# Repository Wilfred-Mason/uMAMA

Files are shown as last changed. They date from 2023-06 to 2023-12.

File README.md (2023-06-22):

# uMAMA
Repository for the development and research of a microfluidic biosignature detection device in the Whyte Lab at Mcgill

# Standard Operating Procedure: uMAMA
## Hardware Setup
**Equipment list**:
1. uMAMA module
2. USB cables for camera and arduino
3. USB hub for field computer

### Instructions
1. Turn field computer on
2. Plug USB hub into field computer (make sure the USB hub switch is on)
3. Plug camera and arduino USB cables into USB hub
4. Wait 1 minute for the camputer to recognize the devices

## Software Setup
**List of Executable Python Scripts**
1. **Main.py**:
   This is your main script that will be used to take measurments with the uMAMA unit
   Run this everytime you need to take a new measurment. The script will prompt you to select
   the uMAMA that you are taking a measurment of and it will allow you to select sampling
   spots for the colours. This script will also save data into the RBG_Data.csv file in the
   respective uMAMA folder. It will also save the photo taken with its date in its folder with the
   format (uMAMA_#_MM-DD-YYYY_HH-MM-SS)
2. **Reset.py**:
   This is the script that will delete previously recorded data.
   You can either select which uMAMA's data to delete or you can delete all uMAMA data.
   This script should be run only before the first uMAMA measurment to delete all data.
3. **EditData.py**:
   This is the script that allows you to edit previous uMAMA data. It allows you to delete
   measurments for the uMAMAs. The script will prompt you for which uMAMA's data you want to
   edit. It will then display a list of all uMAMA measurments with their dates
   in the format (MM-DD-YYYY_HH-MM-SS)
4. **GenerateFigure.py**:
   This script allows you to generate a colour plot using the uMAMA data. It will prompt you
   for which uMAMA's data you would like to visualize. It will save the figure in their respective uMAMA
   folder.

### Intructions
**First Time Measurement**
1. Open Windows PowerShell
2. Enter the uMAMA directory via
   `cd uMAMA`
3. Run the reset script via
   `Python Reset.py`
4. When prompted for which uMAMA's data to delete, enter "a" for all
5. When prompted to confirm the request, enter "y" for yes
6. All the data is now cleared
7. Next, ensure that all uMAMA folders are present. There should be 12 folders with the format (uMAMA_#). Create new folders and edit folder naming in case of any mistakes.
8. You are now good to take your first measurement!

**Trouble Shooting:**
  If the `Reset.py` script returns any errors, you can manually delete all data by entering
  each uMAMA folder and deleting its content (DO NOT DELETE THE uMAMA FOLDERS)

**Taking a Measurement**
1. Open Windows PowerShell
2. Enter the uMAMA directory via
   `cd uMAMA`
3. Run the reset script via
   `Python Main.py`
4. Answer the prompt with which uMAMA you are taking a measurement of (integer between 1 and 12)
5. After a few seconds a window with an image should pop up. The window icon will look like this in your task bar:


6. On the image window, select which spots to sample colour from using the left mouse click. You can undo your last selection with a right mouse click anywhere in the image window
7. When finished selecting 16 spots, click the "esc" key while the image window is slected
8. The script will extract the colours and save them into the RBG_Data.csv file in the
   respective uMAMA folder. It will also save the photo taken with its date in its folder with the
   format (uMAMA_#_MM-DD-YYYY_HH-MM-SS)

**Trouble Shooting:** If you see the error message `ERROR!! Oopsies!! I think you forgot to connect the arduino!` wait a minute for the computer to recognize the arduino. If after a minute it is still giving that error, you may need to change the COM Port. View the intructions for that in the "Changing COM Port" section. <br />
If you see the error message `ERROR!!!!! Hmmm, make sure the camera is connected!!` wait a minute for the computer to recognize the camera. If it gives the same message after a minute, the would mean the camera is malfunctioning and there likley is no solution. A last ditch effort could be to change the selected camera. View the "Changing Camera Selection" section.
If you run into more errors that do not have a clear error message, then run the `TakePhoto.py` script do that we can analyze the data upon return to Mcgill. Hopefully this won't happen!! Sorry if it does!!

**Editing Previous Data**
1. Open Windows PowerShell
2. Enter the uMAMA directory via
   `cd uMAMA`
3. Run the reset script via
   `Python EditData.py`
4. Answer the prompt with which uMAMA's data you want to edit (integer between 1 and 12)
5. The script will list all collected data and their time point in the format (MM-DD-YYYY_HH-MM-SS)
6. To the right of each measurement, an index is present
7. Answer the prompt with the index of the data point that you want to delete

**Trouble Shooting:** There should not be any errors that come up here but if one does, you can manually go into the uMAMA folder and delete the image and row from the CSV file

**Generating a Plot**
1. Open Windows PowerShell
2. Enter the uMAMA directory via
   `cd uMAMA`
3. Run the reset script via
   `Python GenerateFigure.py`
4. Answer the prompt with which uMAMA's data you want visualize (integer between 1 and 12)
5. A plot will pop up with the colour progression of each well's colour
6. The figure will be saved in the folder of each uMAMA

**Trouble Shooting:** There should not be any errors that come up here but if one does, follow the error messages. Date should be saved in the csv files at this point so plots can be generated back at Mcgill

**Taking a Photo**
1. Open Windows PowerShell
2. Enter the uMAMA directory via
   `cd uMAMA`
3. Run the reset script via
   `Python TakePhoto.py`
4. Answer the prompt with which uMAMA you are taking a measurement of (integer between 1 and 12)
5. After a few seconds a window with an image should pop up. The window icon will look like this in your task bar:
  
6. On the image window, click the "y" key if the image is good or click the "n" key to abort the program.
7. The image should save with its date in its folder with the format (uMAMA_#_MM-DD-YYYY_HH-MM-SS)

**Trouble Shooting:** If you see the error message `ERROR!! Oopsies!! I think you forgot to connect the arduino!` wait a minute for the computer to recognize the arduino. If after a minute it is still giving that error, you may need to change the COM Port. View the intructions for that in the "Changing COM Port" section. <br />
If you see the error message `ERROR!!!!! Hmmm, make sure the camera is connected!!` wait a minute for the computer to recognize the camera. If it gives the same message after a minute, the would mean the camera is malfunctioning and there likely is no solution. A last ditch effort could be to change the selected camera. View the "Changing Camera Selection" section.

**Changing COM Ports**<br />
1. Open "Device Manager" in Windows
2. Open the drop down menu labeled "Ports (COM & LPT)"
3. If the arduino is connected, one of the listed ports should be the arduino: <br />
<br />
Remember the COM number for the port <br />
If none of the COM ports apears to be an arduino, remember all of the listed COM numbers. You will have to try them all until the Python script works <br />
4. Open the Python script named "arduinoNano.py" by this pathway: `/uMAMA/src/arduinoNano.py`. To open the script, right click the file and open with IDE. <br />
5. Change the variable named "COMPort" in line 17 to the COM number that was listed in device manager. <br />
6. Save the file and try the script that you originally wanted to run <br />
7. If the problem is not fixed, there isn't much you can do. This may mean that the arduino is busted. <br />

**Changing Camera Selection** <br />
If the camera does not seem to work, you can try changing the camera selection.<br />
However, this will likely not work.  <br />
1. Open the Python script named "camera.py" by this pathway: `/uMAMA/src/camera.py`. To open the script, right click the file and open with IDE.
2. Change the variable named "selection" in line 6 to either 0 or 2. Try both.
3. Save the file and try the script that you originally wanted to run
4. If the problem is not fixed, there isn't much you can do. This may mean that the camera is busted.

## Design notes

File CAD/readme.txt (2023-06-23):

#CAD Contents

1) CAMERA_HOLDER: fixes webcam on CAMERA_MOUNT
2) CAMERA_MOUNT_(SIZE): fixes CAMERA_HOLDER to the INTEGRATED_UNIT, comes in four size (M, L, XL, XXL)
3) INTEGRATED_UNIT: mount for CAMERA_MOUNT_(SIZE), PUMP_MOUNT(s) and the uMAMA module
4) INTEGRATED_UNIT_BASE: base for the INTEGRATED_UNIT
5) LED_CASE_(TOP/BOTTOM): case for the LED circuit and LED
6) NOTCH: used to the fix the LED_CASE_TOP to INTEGRATED_UNIT_BASE
7) LEG: support for the INTEGRATED_UNIT/BASE
8) PUMP_MOUNT: mount for the peristaltic pumps ([product page](https://www.amazon.ca/Gikfun-Peristaltic-Connector-Aquarium-Analytic/dp/B01IUVHB8E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))

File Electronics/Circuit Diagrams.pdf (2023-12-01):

## ARDUINO 1 STEPPER/HEATER CIRCUIT

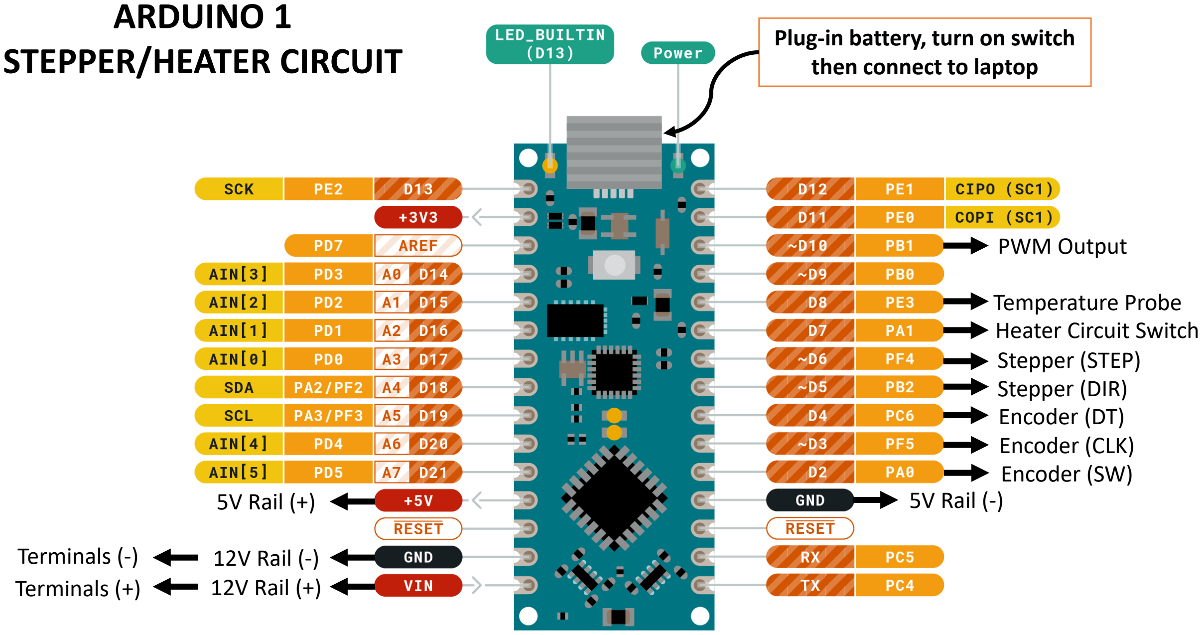
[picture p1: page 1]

5V Rail (+)

12V Rail (-)
12V Rail (+)

5V Rail (-)

Stepper (DIR)

Stepper (STEP)

Encoder (CLK)

Encoder (DT)

Encoder (SW)

PWM Output

Heater Circuit Switch

Temperature Probe

Terminals (+)

Terminals (-)

Plug-in battery, turn on switch then connect to laptop

## ARDUINO 2 FLUIDICS CIRCUIT

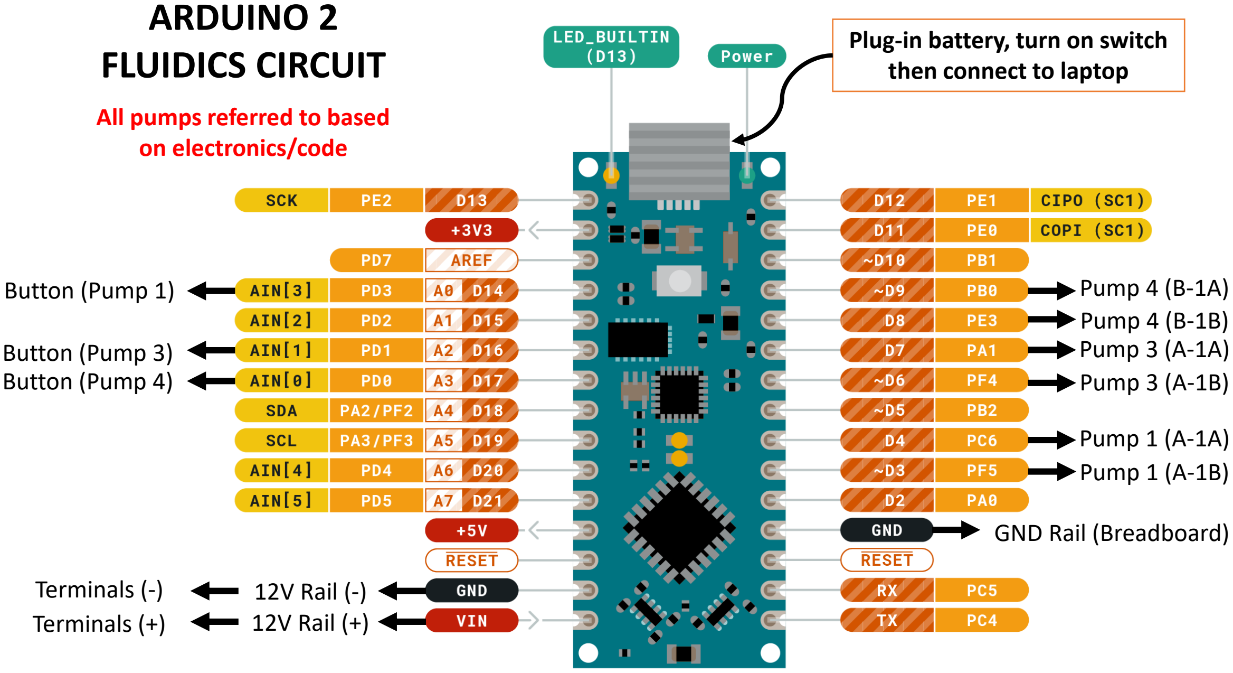
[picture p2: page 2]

12V Rail (-)
12V Rail (+)

GND Rail (Breadboard)

Pump 3 (A-1B)

Pump 1 (A-1B)

Pump 1 (A-1A)

Button (Pump 1)

Button (Pump 3)
Button (Pump 4)

Pump 3 (A-1A)

Pump 4 (B-1B)

Pump 4 (B-1A)

Plug-in battery, turn on switch then connect to laptop

Terminals (+)

Terminals (-)

All pumps referred to based on electronics/code

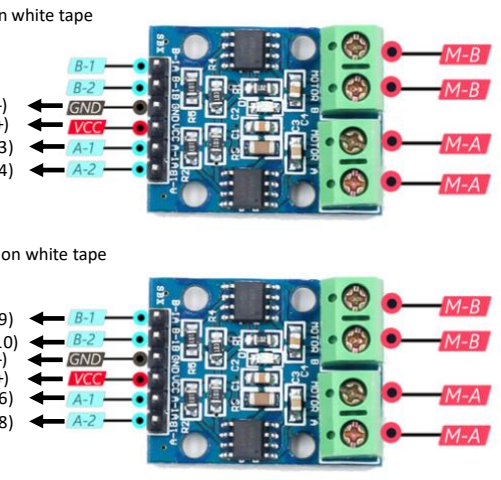
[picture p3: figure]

ARDUINO (D3)
ARDUINO (D4)

ARDUINO (D6)
ARDUINO (D8)

ARDUINO (D9)
ARDUINO (D10)

Terminals (+)

Terminals (-)

Terminals (+)

Terminals (-)

Motor Driver 1: “1” on white tape

Motor Driver 2: “3 4” on white tape

## PUMP 4 (ELECTRONICS CIRCUIT AND CODE) is PUMP 1 in the physical device PUMP 3 (ELECTRONICS CIRCUIT AND CODE) is PUMP 2 in the physical device PUMP 1 (ELECTRONICS CIRCUIT AND CODE) is PUMP 3 in the physical device

## SWITCH: PUMP 4 (ELECTRONICS AND CODE) connected to pin D17 SWITCH: PUMP 3 (ELECTRONICS AND CODE) connected to pin D16 SWITCH: PUMP 1 (ELECTRONICS AND CODE) connected to pin D14

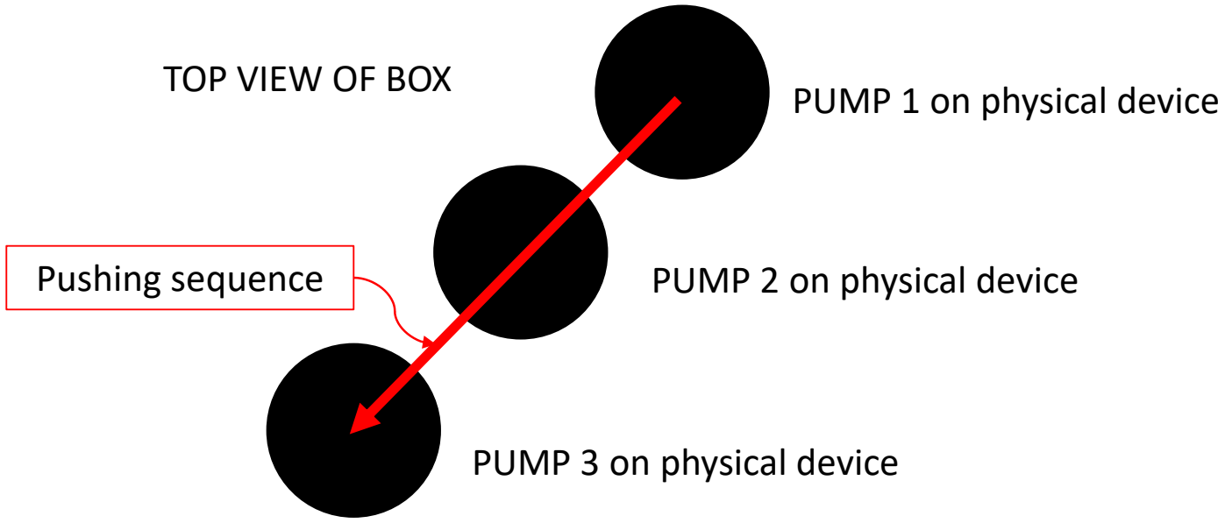
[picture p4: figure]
TOP VIEW OF BOX; PUMP 1 on physical device; PUMP 2 on physical device; PUMP 3 on physical device; Pushing sequence
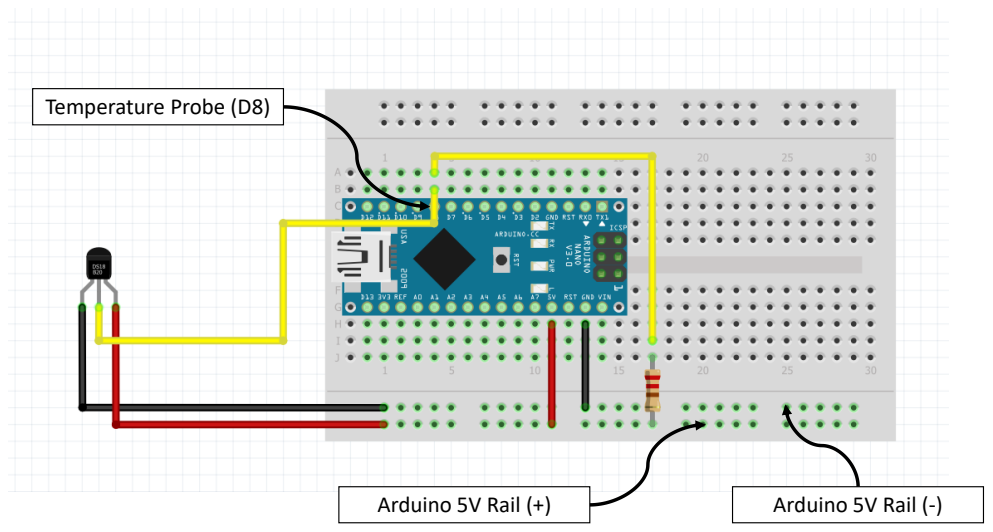
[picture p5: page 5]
Temperature Probe (D8); Arduino 5V Rail (+); Arduino 5V Rail (-)

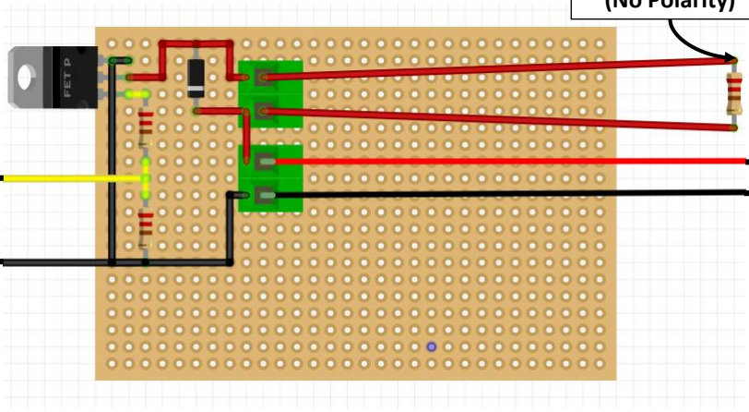
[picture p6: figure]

PWM Output (D10)

ARDUINO GND
(12V Rail, “-” Side)

Terminals (“-”)

Terminals (“+”)

Cartridge Heater
(No Polarity)

Stepper (STEP, D6)

Stepper (DIR, D5)

Arduino 5V Rail (+)

Arduino 5V Rail (+)

Arduino 5V Rail (

)

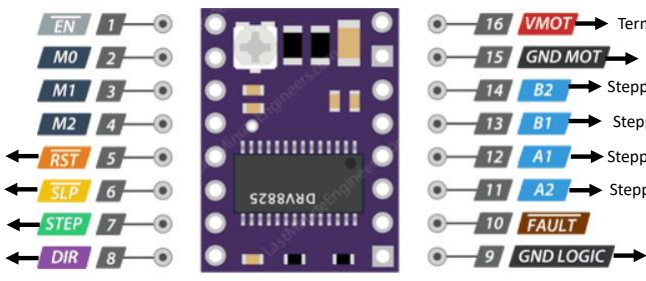
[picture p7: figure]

Terminals (+)

Terminals (

)

Stepper (Black)

Stepper (Green)

Stepper (Red)

Stepper (Blue)

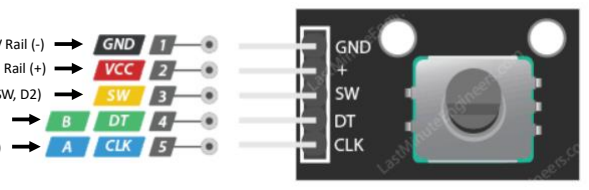
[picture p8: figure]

Encoder (CLK, D3)

Encoder (DT, D4)

Encoder (SW, D2)

Arduino 5V Rail (+)

Arduino 5V Rail (-)

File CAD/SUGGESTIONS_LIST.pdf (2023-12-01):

Whyte Lab | Integration Improvements Summary | Summer 2022
1 | P a g e

Contents

2 | P a g e

Improvements

Press-Fits

The press-fit between 3D-printed parts and the bearing loosened over time due to vibrations and

regular use. The 3D-printed components that are press-fit onto the bearing are

“Bearing_Ring_Final” and “Base_Final”. To increase the tightness of the fit and prevent

loosening one could try adding epoxy or superglue between the press-fit components. One could

also try to change the tolerances on the parts to allow for a tighter fit. The best interference fit

should be achieved when the diameter of the 3D-printed part is approximately equal to the diameter

of the bearings +/- 0.1 mm.

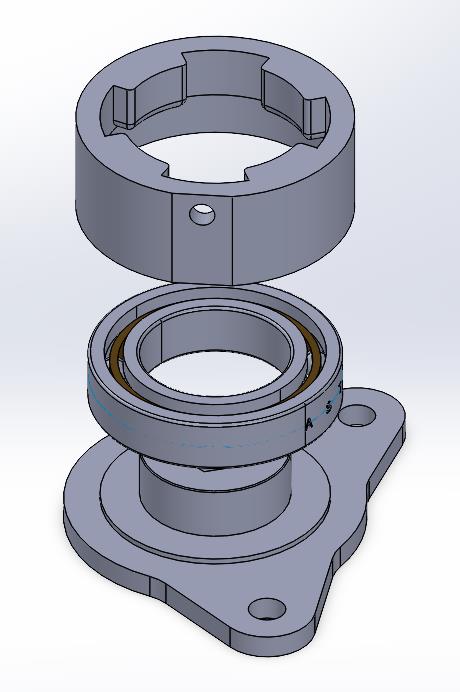
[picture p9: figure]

Press-fit components in the assembly

Loose Components

With regular use and vibrations, the connections between “Bearing_Ring_Final” and

“Arm_Final” loosened. Note that this connection is accomplished with a single screw (fed

through “Bearing_Ring_Final”) and a captive nut in the “Arm_Final” part. To reduce play

between the parts, two or three more captive nuts can be added to “Arm_Final”. To prevent the

screws from loosening, one can add a thread locker (e.g., Loctite).

3 | P a g e

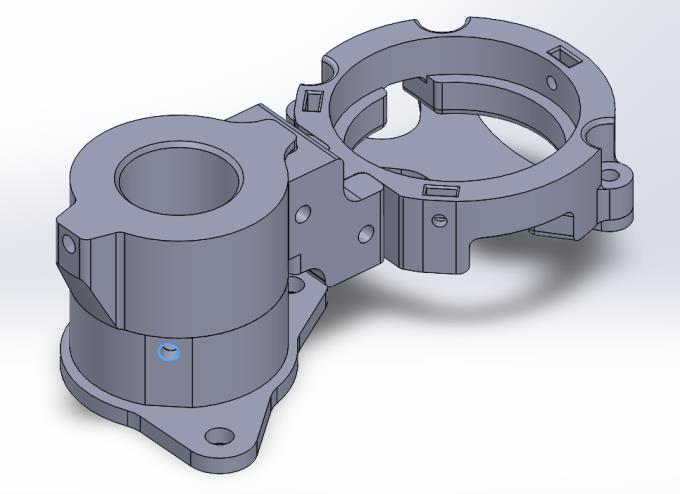
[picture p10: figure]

Single hole which accommodates a screw which threads into a captive nut in “Arm_Final”

Heating Source

The heating source successfully heated up the melting cup however there were a couple of issues.

First, the heating unit is difficult to mount. It requires the part “Cap_Final_Large” to support the

silicon sock which holds the temperature probe and the cartridge heater. One improvement would

be to replace the current mounting method (which using screws and nuts) with a clip-on method

leveraging the flexibility of thin 3D-printed components.

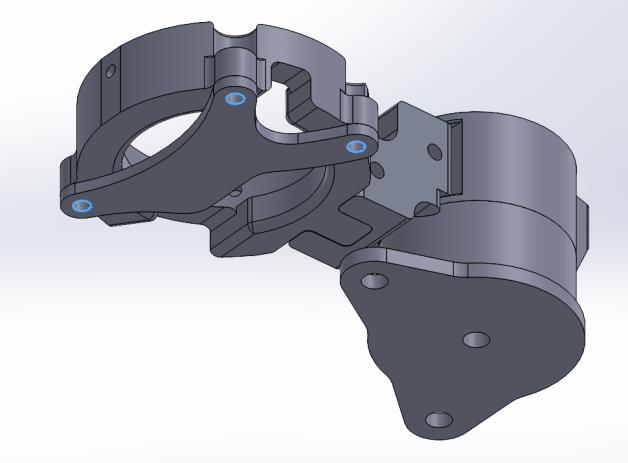
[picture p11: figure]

Bracket named “Cap_Final_Large” mounted to the underside of “Cup_Final”. The bracket is

mounted to “Cup_Final” using screws which feed through both parts, and nuts.

Another issue with heating source is that it requires a custom silicone sock to hold the components.

The silicone sock is manufactured using RTV silicone (thermal gasket material) and a custom, 3D-

printed mould consisting of the parts, “Silicone_Sock_Side(s)”, “Silicone_Sock_Top_Bottom”,

4 | P a g e
and | “Silicone_Sock_Rod(s)”. | One | improvement | would | be | to | replace | the | part

“Silicone_Sock_Rod(s)” by aluminum rods with an equivalent diameter. Metal rods would be

less prone to breaking and could be easier to extract with hand tools.

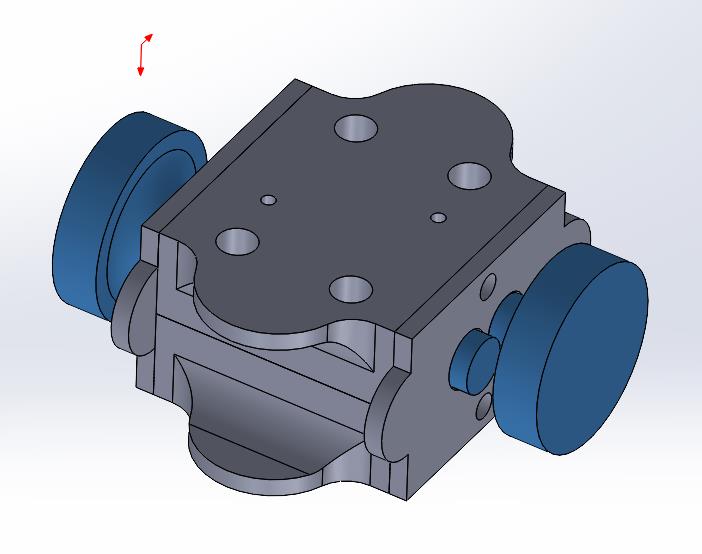
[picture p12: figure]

The silicone mould, the parts “Silicone_Sock_Rod(s)” can be replaced by aluminum rods

Since the cartridge heater is cylindrical, there can only be a line of contact between it and a flat

surface. To maximize heat transfer, the cartridge heater was mounted in a thermally conductive

silicone sock. The silicone sock served to enable a plane of contact with the bottom of the cup. An

alternative to the cartridge heater is a nichrome-wire coil (or another similar material) embedded

in silicone and adhered to the bottom of the melting cup. It may also be possible to design a PCB

which incorporates a resistive, heating coil. An example of this is shown in the following video,

https://www.youtube.com/watch?v=2cvDjeSUgwY.

An issue with the temperature probe is that is large relative to the size of the melting cup. It is also

cylindrical meaning that it needed to be mounted in a silicone sock to enable a plane of contact

with the melting cup. An alternative to the temperature probe used in the first prototype is a

thermocouple. The thermocouple can be mounted with silicone directly to the underside of the

cup. The thermocouple will require a voltage divider.

5 | P a g e

Melting Cup

The melting cup mounts directly in the 3D-printed part, “Cup_Final”. The aluminum melting cup

is ribbed and “Cup_Final” has diametrical tolerances such that the two parts snap into each other.

To further secure the melting cup in the 3D-printed part, three set-screws with captive nuts were

added. To reduce assembly time, the number of set-screws can probably be reduced to one or two.

The main issue with “Cup Final” is that the exiting tube (which connects to the fluidics module

via a peristaltic pump) tends to interfere with the drill when the melting cup assembly is retracted,

and the drill is boring. To solve this problem, the tube exit port should be moved to the other side

of “Cup_Final”. However, since the other side already contains the exit port for the temperature

probe and cartridge heater wires, some re-arranging will be necessary to ensure that all the

components can fit.

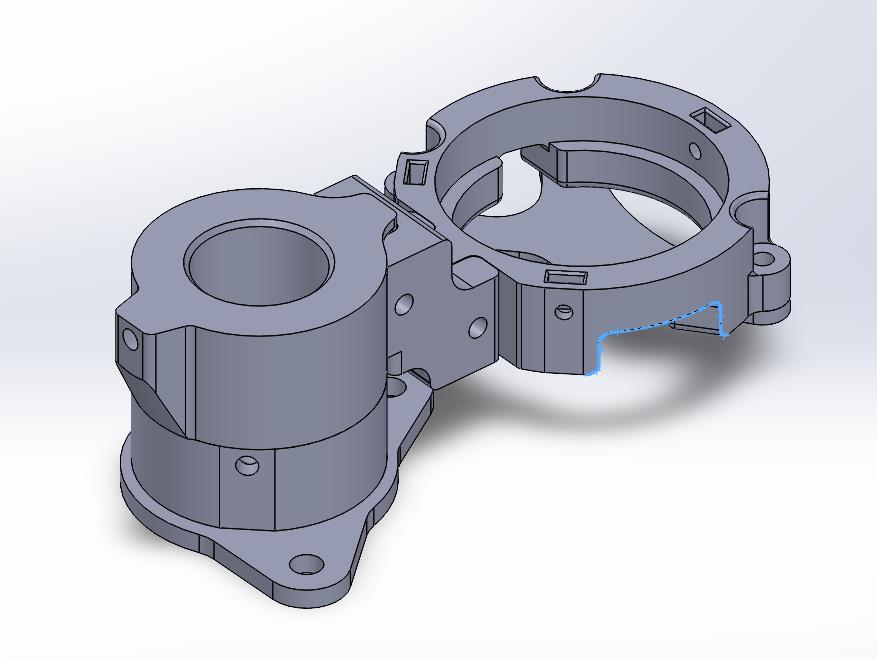
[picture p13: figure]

Exit port for the tube in the 3D-printed part “Cup_Final”

Electronics

The electronics all worked however there were several issues with connections. First, the

connections to the stepper motor and the three pumps should be changed to JST or MOLEX. In

the current prototype, screw terminals soldered to a perf-board and mounted in a 3D-printed case

are used for connections. The connections to the temperature probe and cartridge heater or

thermocouple and heating coil should be swapped from JST or MOLEX connectors as well.

6 | P a g e

The electronics fit within a fairly large case. To make the electronics more compact, a custom

PCB should be made for the heater/stepper motor control circuit. The PCB would incorporate

headers to mount the Arduino and connections for the stepper driver and transistor. Another PCB

could be made for the fluidics module. This PCB would also have headers to mount the Arduino.

To save more space, the current H-Bridge modules could be substituted for three compact

L9110H chips. These modules can be directly soldered onto the PCB.

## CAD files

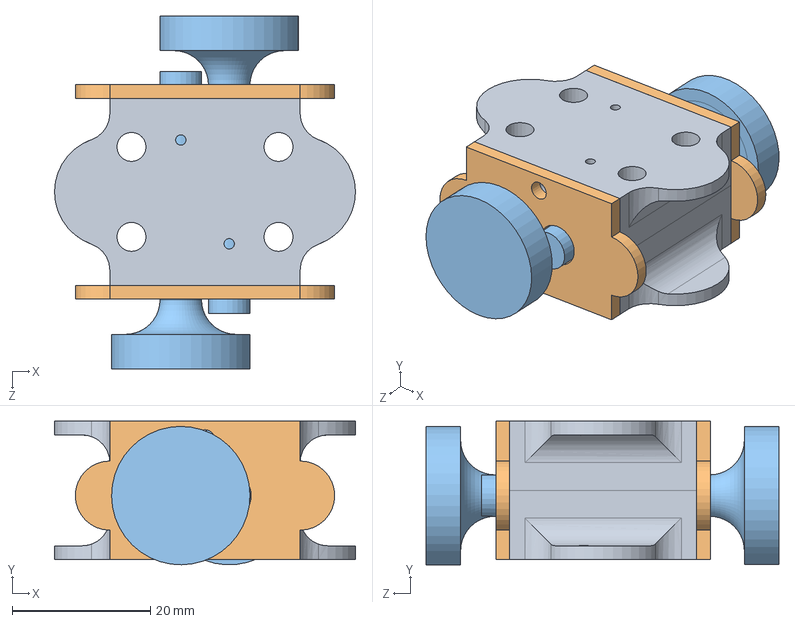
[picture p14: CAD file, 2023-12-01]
CAD/MELT_CUP_ASSEMBLY/Silicone Sock CAD/Silicone_Sock_Assembly.SLDASM
43.5 x 20.7 x 51.0 mm
Silicone_Sock_Top_Bottom x 2
Silicone_Sock_Side(s) x 2
Silicone_Sock_Rod(s) x 2

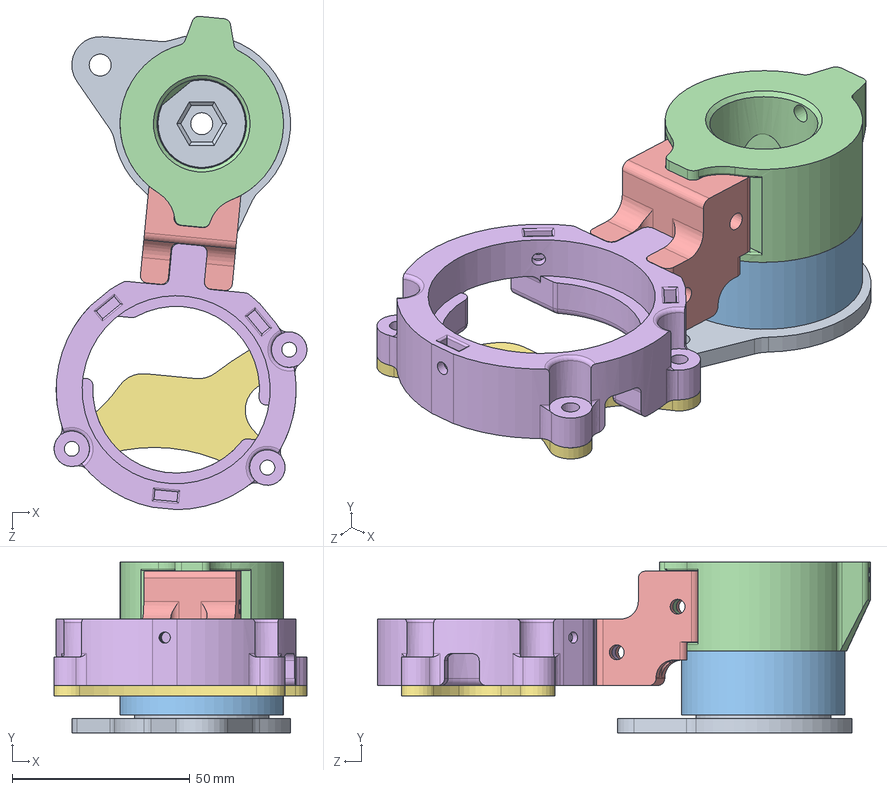
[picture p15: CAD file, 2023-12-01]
CAD/MELT_CUP_ASSEMBLY/Assembly_Full.SLDASM
71.2 x 48.0 x 138.8 mm
Base_Final
AST_Bearings_6905.stp
Bearing_Ring_Final
Arm_Final
Connector_Final
Cup_Final
Cap_Final_Large

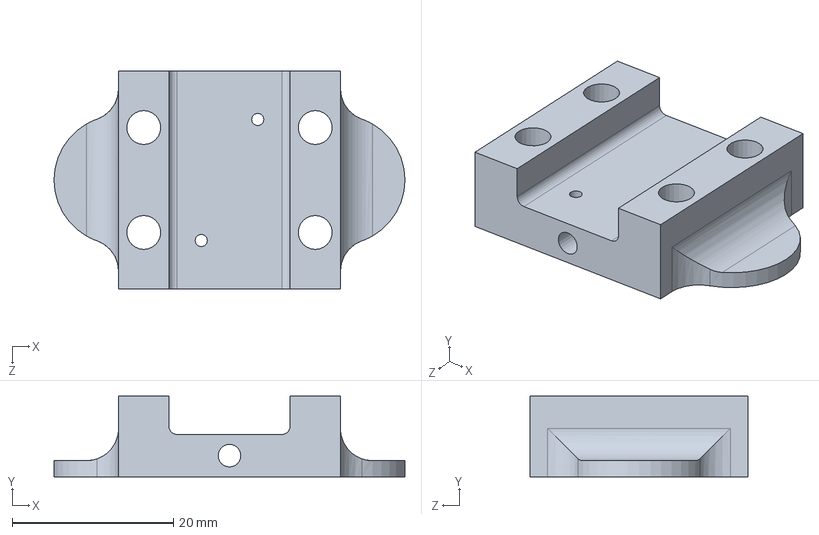
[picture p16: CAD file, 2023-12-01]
CAD/MELT_CUP_ASSEMBLY/Silicone Sock CAD/Silicone_Sock_Top_Bottom.SLDPRT
43.5 x 10.0 x 27.0 mm

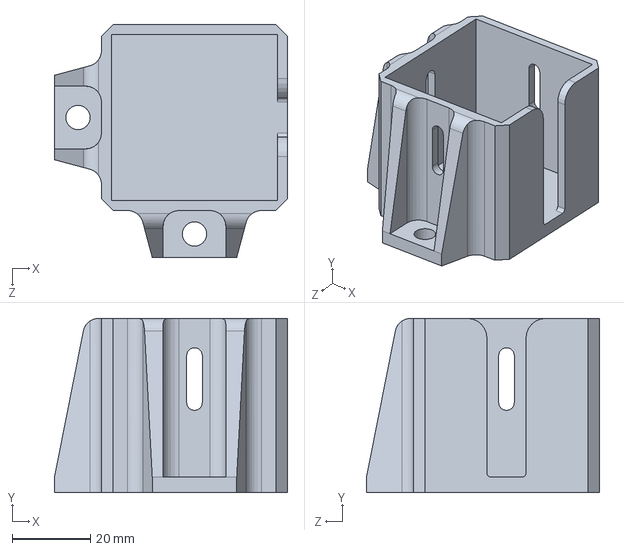
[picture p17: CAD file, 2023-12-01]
CAD/MELT_CUP_ASSEMBLY/Stepper_Mounts/Stepper_Motor_V4.SLDPRT
59.5 x 44.5 x 59.5 mm

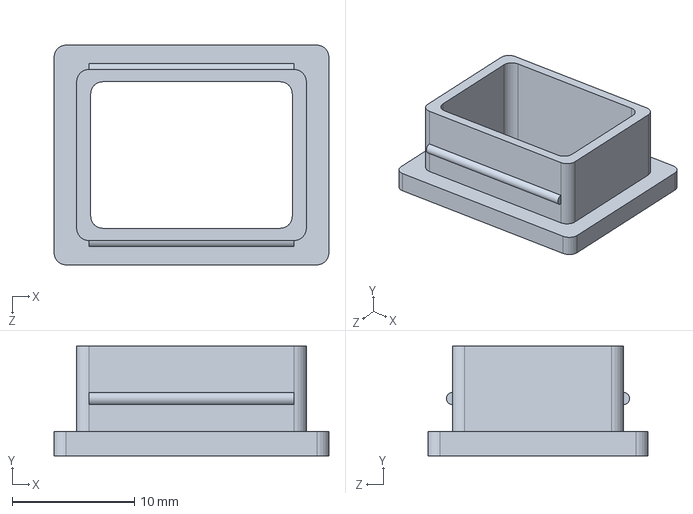
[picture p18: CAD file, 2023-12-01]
CAD/MELT_CUP_ASSEMBLY/USB_Port.SLDPRT
22.5 x 9.00 x 18.0 mm

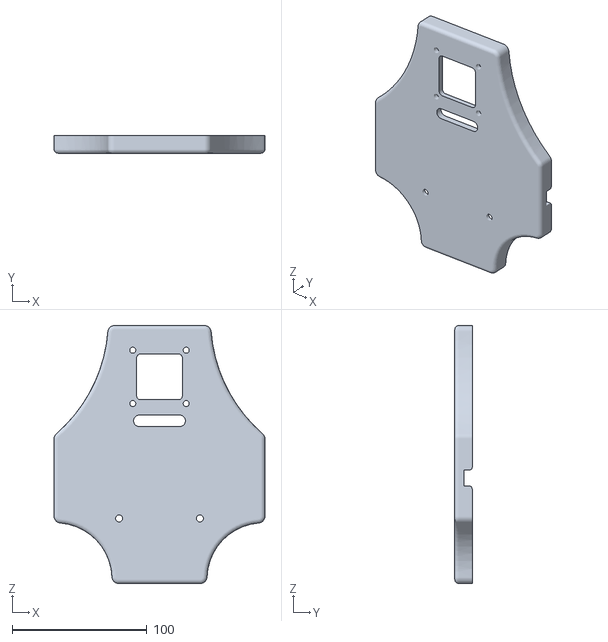
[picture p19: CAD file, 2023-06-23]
CAD/VISION_PUMP_ASSEMBLY/INTEGRATED_UNIT_BASE.STL
156.6 x 13.0 x 191.6

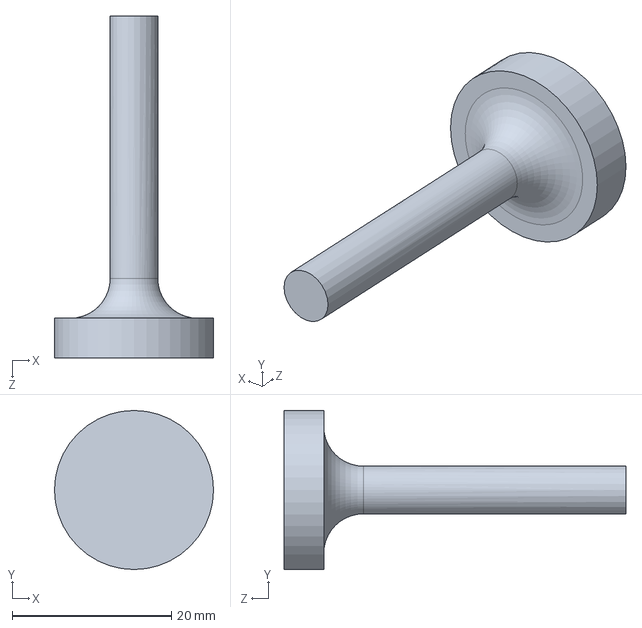
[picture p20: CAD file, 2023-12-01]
CAD/MELT_CUP_ASSEMBLY/Silicone Sock CAD/Silicone_Sock_Rod(s).SLDPRT
20.0 x 20.0 x 43.0 mm

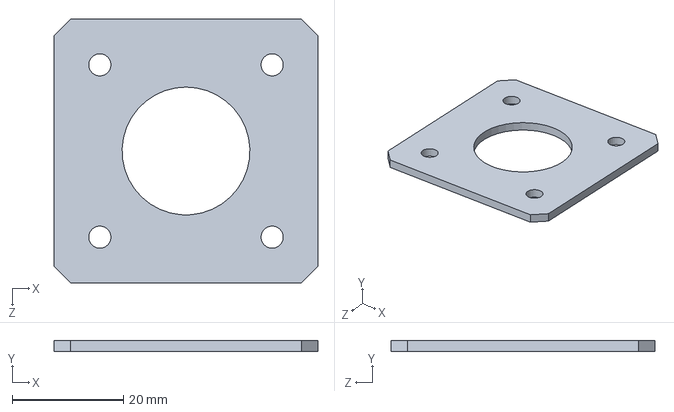
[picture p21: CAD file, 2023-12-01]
CAD/MELT_CUP_ASSEMBLY/Stepper_Mounts/Stepper_Mount_Lid_V4.SLDPRT
47.5 x 2.00 x 47.5 mm

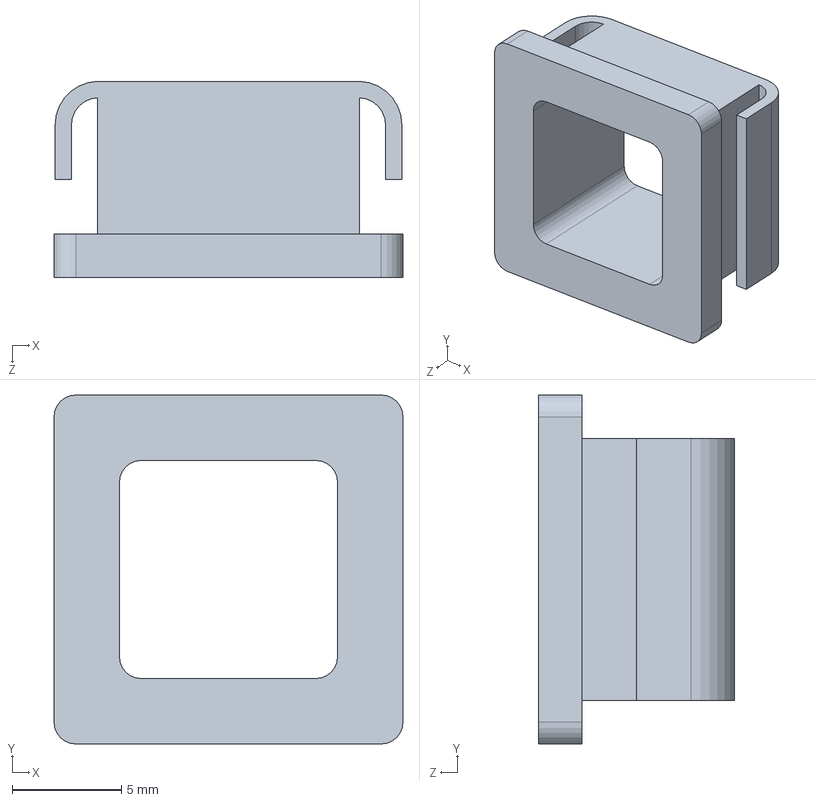
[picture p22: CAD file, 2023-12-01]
CAD/MELT_CUP_ASSEMBLY/Wire_Port_Final.SLDPRT
16.0 x 16.0 x 9.00 mm

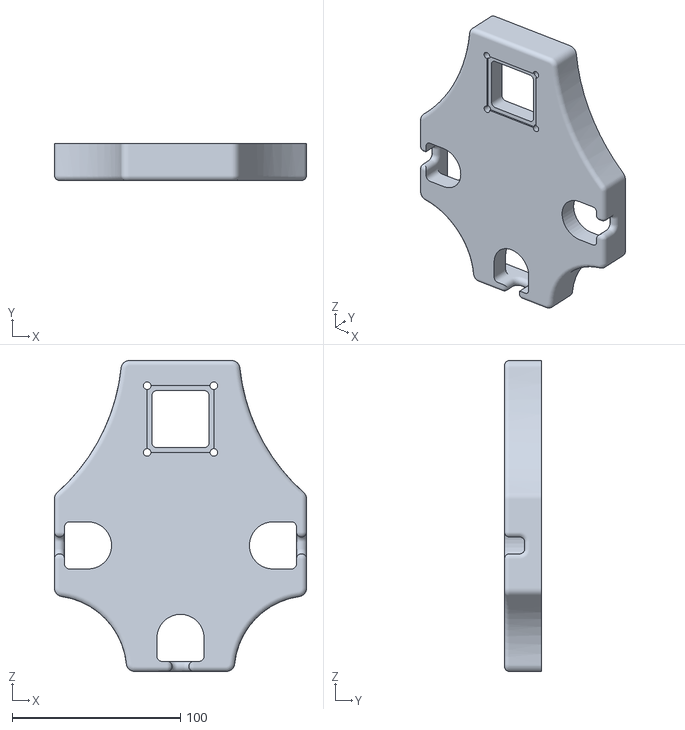
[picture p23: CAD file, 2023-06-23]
CAD/VISION_PUMP_ASSEMBLY/INTEGRATED_UNIT.STL
150.0 x 22.0 x 185.0

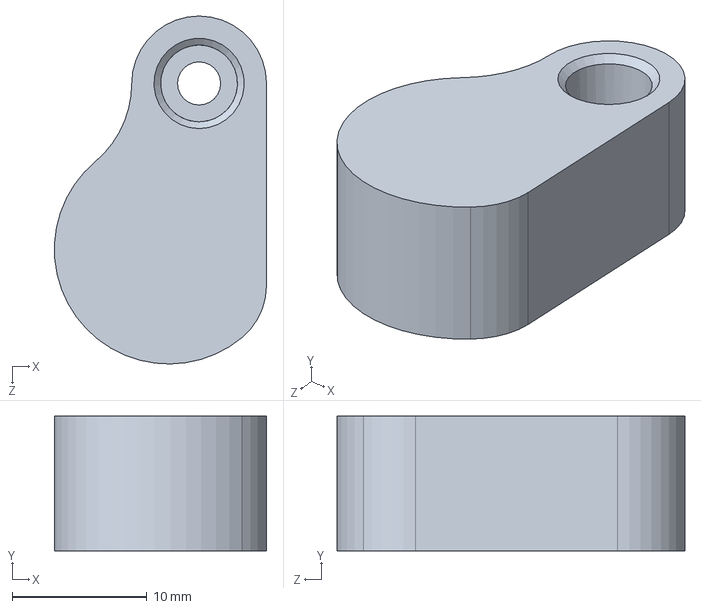
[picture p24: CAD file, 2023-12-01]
CAD/MELT_CUP_ASSEMBLY/Idler_Tensioner_Final.SLDPRT
15.7 x 10.0 x 25.8 mm

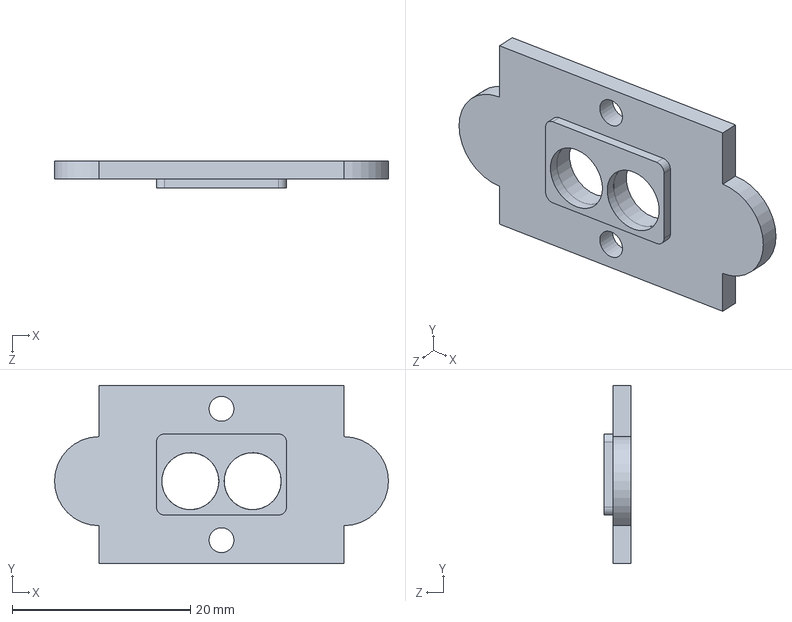
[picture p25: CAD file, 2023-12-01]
CAD/MELT_CUP_ASSEMBLY/Silicone Sock CAD/Silicone_Sock_Side(s).SLDPRT
37.5 x 20.0 x 3.00 mm

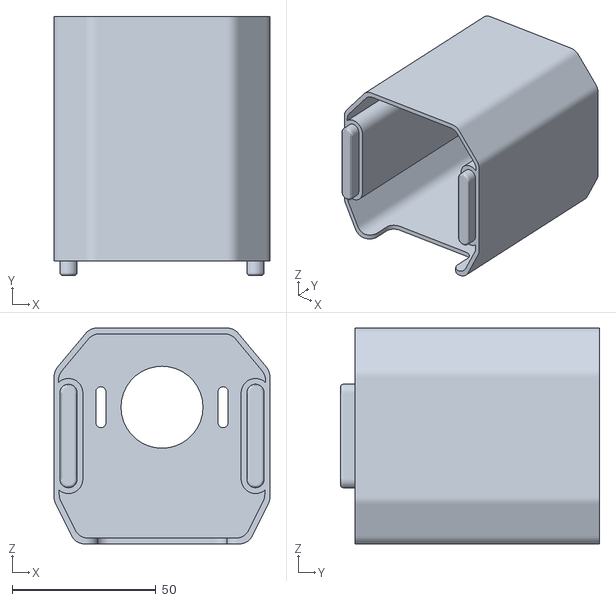
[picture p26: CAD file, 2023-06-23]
CAD/VISION_PUMP_ASSEMBLY/CAMERA_MOUNT_XXL.STL
75.0 x 90.0 x 75.0

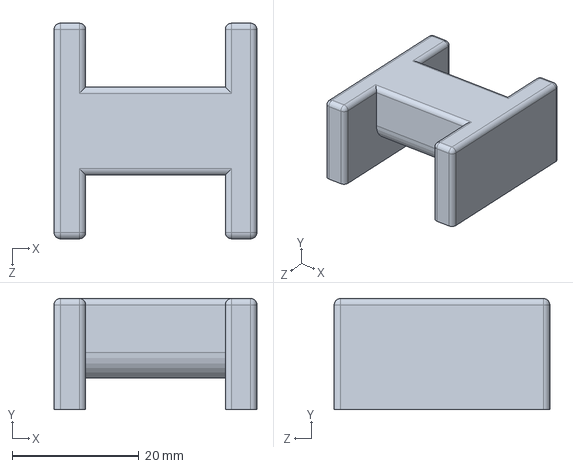
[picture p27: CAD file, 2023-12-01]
CAD/MELT_CUP_ASSEMBLY/Wire_Case.SLDPRT
32.0 x 17.5 x 34.0 mm

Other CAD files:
CAD/VISION_PUMP_ASSEMBLY/CAMERA_MOUNT_L.STL
CAD/MELT_CUP_ASSEMBLY/Arm_Final.SLDPRT
CAD/VISION_PUMP_ASSEMBLY/LED_CASE_TOP.STL
CAD/MELT_CUP_ASSEMBLY/Electronics_Mount_Final.SLDPRT
CAD/MELT_CUP_ASSEMBLY/Arm_Final.STL
CAD/MELT_CUP_ASSEMBLY/Base_Final.SLDPRT
CAD/MELT_CUP_ASSEMBLY/Base_Final.STL
CAD/MELT_CUP_ASSEMBLY/Bearing_Ring_Final.SLDPRT
CAD/MELT_CUP_ASSEMBLY/Bearing_Ring_Final.STL
CAD/MELT_CUP_ASSEMBLY/Cap_Final.SLDPRT
CAD/MELT_CUP_ASSEMBLY/Cap_Final_Large.SLDPRT
CAD/MELT_CUP_ASSEMBLY/Cap_Final_Large.STL
CAD/MELT_CUP_ASSEMBLY/Connector_Final.SLDPRT
CAD/MELT_CUP_ASSEMBLY/Connector_Final.STL
CAD/MELT_CUP_ASSEMBLY/Cup_Final.SLDPRT
CAD/MELT_CUP_ASSEMBLY/Cup_Final.STL
CAD/MELT_CUP_ASSEMBLY/Electronics_Mount_Final.STL
CAD/MELT_CUP_ASSEMBLY/Idler_Tensioner_Final.STL
CAD/MELT_CUP_ASSEMBLY/Stepper_Mounts/Stepper_Motor_V4.STL
CAD/MELT_CUP_ASSEMBLY/Stepper_Mounts/Stepper_Mount_Lid_V4.STL
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

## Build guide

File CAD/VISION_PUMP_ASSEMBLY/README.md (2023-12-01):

# Overview of System Hardware

## CAD Contents

1) [CAMERA_HOLDER](CAMERA_HOLDER.STL): fixes webcam on [CAMERA_MOUNT_(SIZE)](CAMERA_MOUNT_M.STL)
2) [CAMERA_MOUNT_(SIZE)](CAMERA_MOUNT_M.STL): fixes [CAMERA_HOLDER](CAMERA_HOLDER.STL) to the [INTEGRATED_UNIT](INTEGRATED_UNIT.STL), comes in four sizes (M, L, XL, XXL)
3) [INTEGRATED_UNIT](INTEGRATED_UNIT.STL): mount for [CAMERA_MOUNT_(SIZE)](CAMERA_MOUNT_M.STL), [PUMP_MOUNT(s)](PUMP_MOUNT.STL) and the uMAMA module
4) [INTEGRATED_UNIT_BASE](INTEGRATED_UNIT_BASE.STL): base for the [INTEGRATED_UNIT](INTEGRATED_UNIT.STL)
5) [LED_CASE_TOP](LED_CASE_TOP.STL), [LED_CASE_BOTTOM](LED_CASE_BOTTOM.STL): case for the LED + circuit
6) [NOTH](NOTCH.STL): used to the fix the [LED_CASE_TOP](LED_CASE_TOP.STL) to [INTEGRATED_UNIT_BASE](INTEGRATED_UNIT_BASE.STL)
7) [LEG](LEG.STL): support for [INTEGRATED_UNIT](INTEGRATED_UNIT.STL) and [INTEGRATED_UNIT_BASE](INTEGRATED_UNIT_BASE.STL)
8) [PUMP_MOUNT](PUMP_MOUNT.STL): mount for the peristaltic pumps ([product page](https://www.amazon.ca/Gikfun-Peristaltic-Connector-Aquarium-Analytic/dp/B01IUVHB8E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))

## Final Assembly

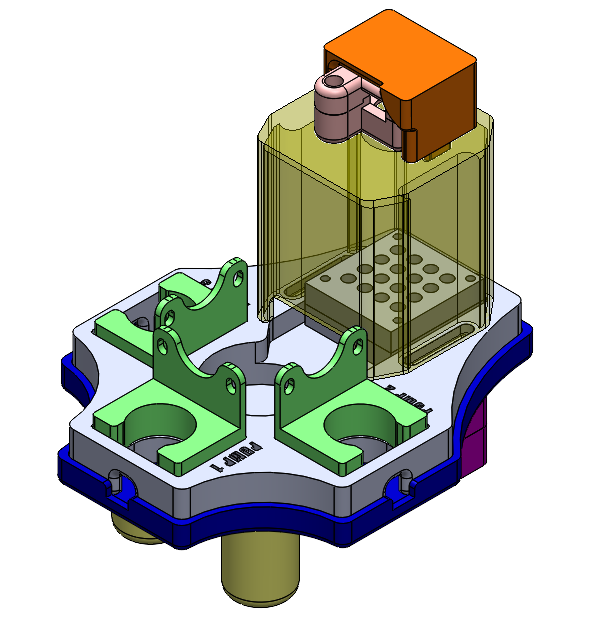
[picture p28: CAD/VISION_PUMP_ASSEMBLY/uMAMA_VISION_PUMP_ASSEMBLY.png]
Assembly


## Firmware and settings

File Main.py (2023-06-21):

import cv2
import numpy as np
import serial
import csv
import src.arduinoNano as arduinoNano
import src.camera as camera
import time
from datetime import datetime
import EditData


circleCentres = []

def click_event(event, x, y, flags, param):
    if event == cv2.EVENT_LBUTTONDOWN:
        newClearFrame = clearFrame.copy()
        circleCentres.append(((x,y), 3))
        addFrame = camera.generateMask(newClearFrame, circleCentres)
        cv2.imshow("image", addFrame)
    if event == cv2.EVENT_RBUTTONDOWN:
        newClearFrame = clearFrame.copy()
        try:
            circleCentres.pop()
        except:
            print("No more circles left to remove!")
            pass
        subFrame = camera.generateMask(newClearFrame, circleCentres)
        cv2.imshow("image", subFrame)



if __name__ == "__main__":
    try:
        arduino = serial.Serial(arduinoNano.COMPort, 9600, timeout=0) #connect to arduino (change COM port if nessisary)
        arduinoNano.turnOffLight(arduino)
    except:
        print("ERROR!! Oopsies!! I think you forgot to connect the arduino! If the arduino is connected, hold your horses!! It may take a minute for the computer to detect the arduino")
        quit()

    uMAMA = input("Which uMAMA are you measuring? (input: integer 1 - 12): ")
    if (int(uMAMA) > 12 or int(uMAMA) < 1):
        print("That was an invalid input, you need to specify the uMAMA plate by an integer between 1 and 12")
        quit()

    print("working...")
    cam = cv2.VideoCapture(1) #initiate camera

    print("working...")

    arduinoNano.turnOnLight(arduino) #send signal to turn on backlight
    time.sleep(0.1)

    try:
        frame = camera.capture(cam)
        clearFrame = frame.copy()
    except:
        print("ERROR!!!!! Hmmm, make sure the camera is connected!! If the camera is connected, wait a tad bit longer, it may take a minute for the computer to detect the camera")
        quit()

    print("Select all of your sampling spots on the image using the left mouse click. To undo your last spot, use the right mouse click. When finished, click the 'Esc' key")
    cv2.imshow('image', frame)
    cv2.setMouseCallback('image', click_event)
    cv2.waitKey(0)
    
    if len(circleCentres) != 16:
        print("Oh no! You didnt select 16 sampling spots. You need to run this program again :/")
        quit()

    circleCentres = camera.sortCircles(circleCentres)

    colours = camera.extractColour(clearFrame, circleCentres, uMAMA)

    EditData.addRow(uMAMA, colours)
    arduinoNano.turnOffLight(arduino)
    print("Data has been saved in 'uMAMA_"+ uMAMA + "/RGB_Data.csv' and image has been stored in 'uMAMA_"+uMAMA+"' folder")

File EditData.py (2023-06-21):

import csv
import pandas

def addRow(uMAMA, data):
    DataFile = open('uMAMA_'+ uMAMA + '/RGB_Data.csv', 'a', newline="")
    DataFile.truncate()
    writer = csv.writer(DataFile)
    writer.writerow(data)

header = ["Date and Time", "1", "2", "3", "4", "5", "6", "7", "8", "9", "10", "11", "12", "13", "14", "15", "16", "17", "18", "19", "20", "21", "22", "23", "24", "25", "26", "27", "28", "29", "30", "31", "32", "33", "34", "35", "36", "37", "38", "39", "40", "41", "42", "43", "44", "45", "46", "47", "48"]

if __name__ == "__main__":
    uMAMA = input("Which uMAMA's data do you want to edit? ")
    try:
        df = pandas.read_csv('uMAMA_'+ uMAMA+'/RGB_Data.csv', names= header)
    except:
        print("Hmmmm I don't think you have taken a measurment of uMAMA "+ uMAMA +" yet")
        quit()
    print("Measurements taken at:")
    print("     Date and Time")
    print(df["Date and Time"])
    rowToDrop = int(input("Provide the index of the measurement you would like to delete: "))
    dropped = df.iloc[rowToDrop, 0]
    df = df.drop([rowToDrop])
    df.to_csv('uMAMA_'+ uMAMA+'/RGB_Data.csv', index= None, header= None)
    print("Measurement at: " + dropped + " was deleted")

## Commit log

2023-06-20 Adding all files
    [RGB_Data.csv]
2023-06-23 CAD folder created
2023-06-23 CAD files uploaded
    [CAMERA_HOLDER.STL, CAMERA_MOUNT_L.STL, CAMERA_MOUNT_M.STL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]
2023-12-01 CAD and schematics
    [Arm_Final.SLDPRT, Arm_Final.STL, Assembly_Full.SLDASM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]
